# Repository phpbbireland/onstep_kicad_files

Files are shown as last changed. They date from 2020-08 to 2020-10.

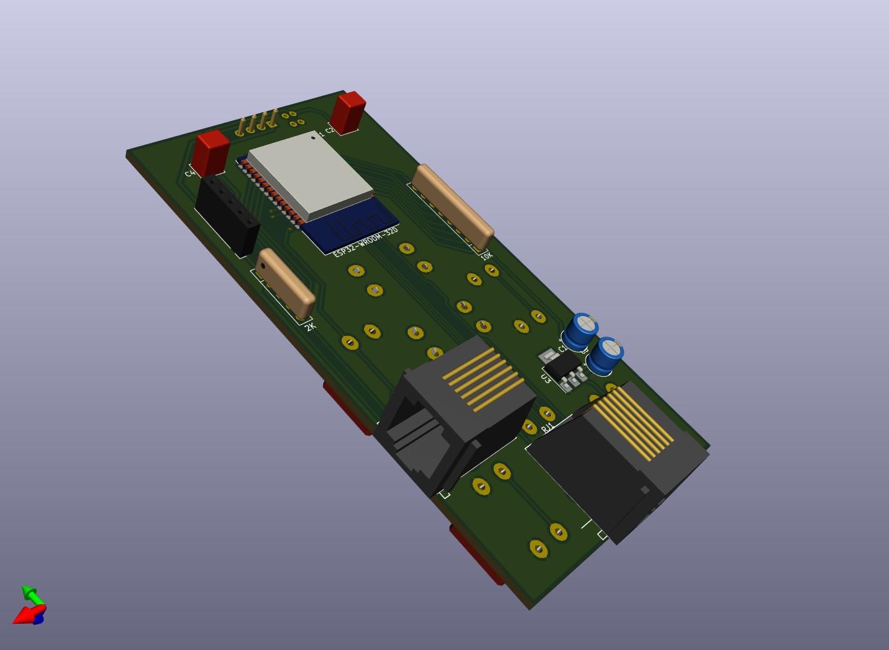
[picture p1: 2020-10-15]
Controller_Version_5.0_SMD_Git/OSHC_ESP32VROOM_Version.jpg

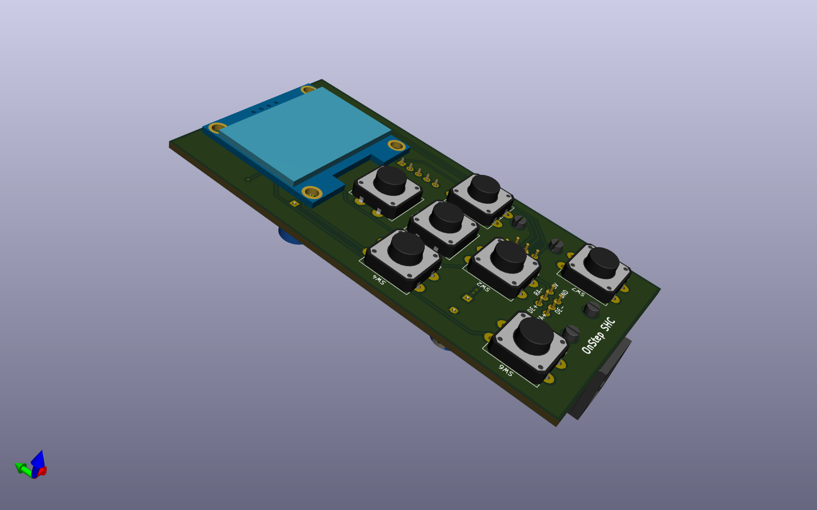
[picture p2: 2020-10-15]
Controller_Version_5.0_SMD_Git/pcb_top.png

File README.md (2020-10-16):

# onstep_kicad_files
Kicad Support Files for OnStep

Here I will Add support files for developing OnStep with Kicad (& FreeCAD where available)...

I have issues access my git repos... appears to be a password/username mismatch... no idea what's up...

The folder: Controller_Version_5.0_SMD_Git contains dev material and is not currently working... possible track errors...

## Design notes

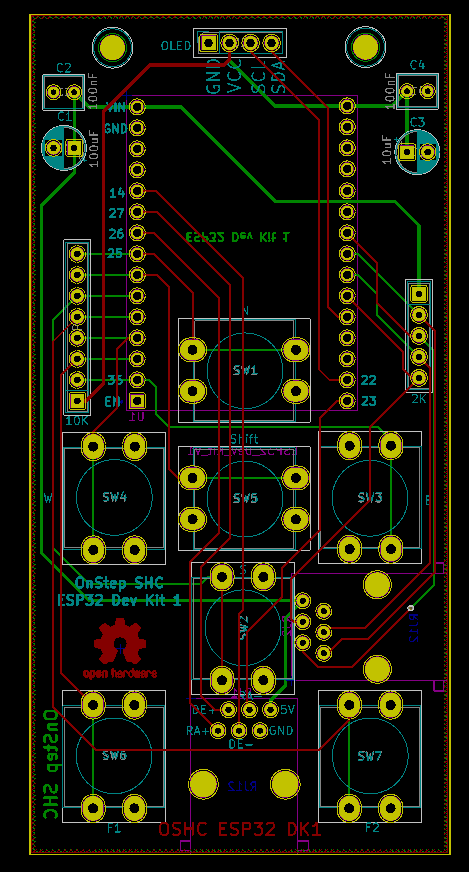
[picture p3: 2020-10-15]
Controller_Version_5.0_SMD_Git/pcb.png

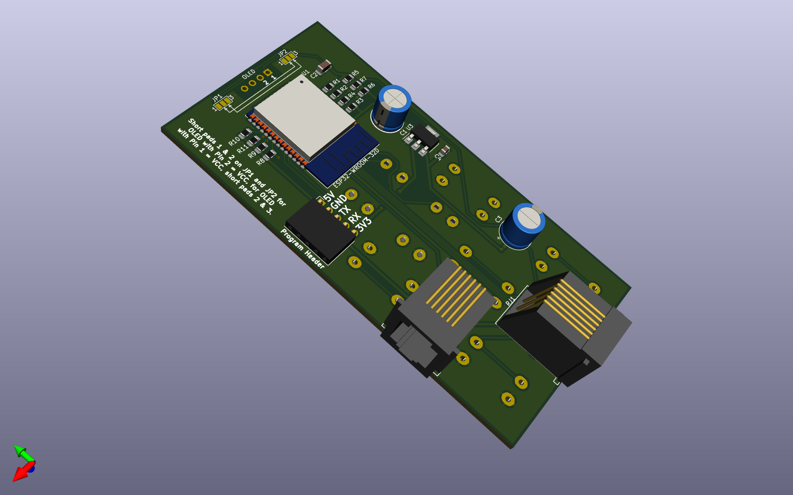
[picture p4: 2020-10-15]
Controller_Version_5.0_SMD_Git/pcb_bottom.png

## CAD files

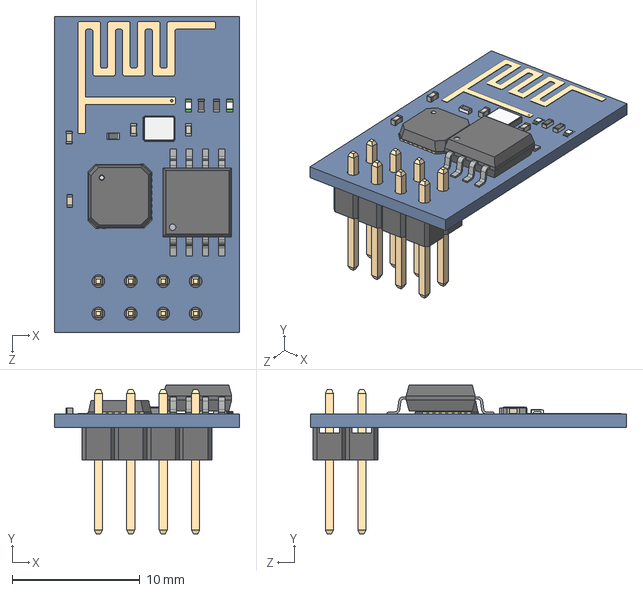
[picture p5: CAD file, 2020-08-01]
ESP8266.step
14.5 x 11.7 x 24.8 mm

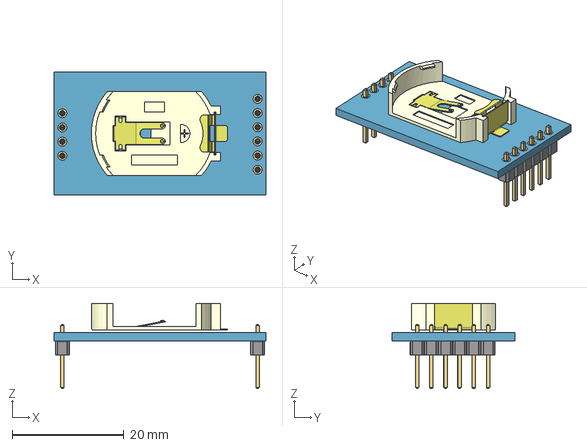
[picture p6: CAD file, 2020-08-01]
DS3231.step
38.0 x 22.0 x 15.3 mm

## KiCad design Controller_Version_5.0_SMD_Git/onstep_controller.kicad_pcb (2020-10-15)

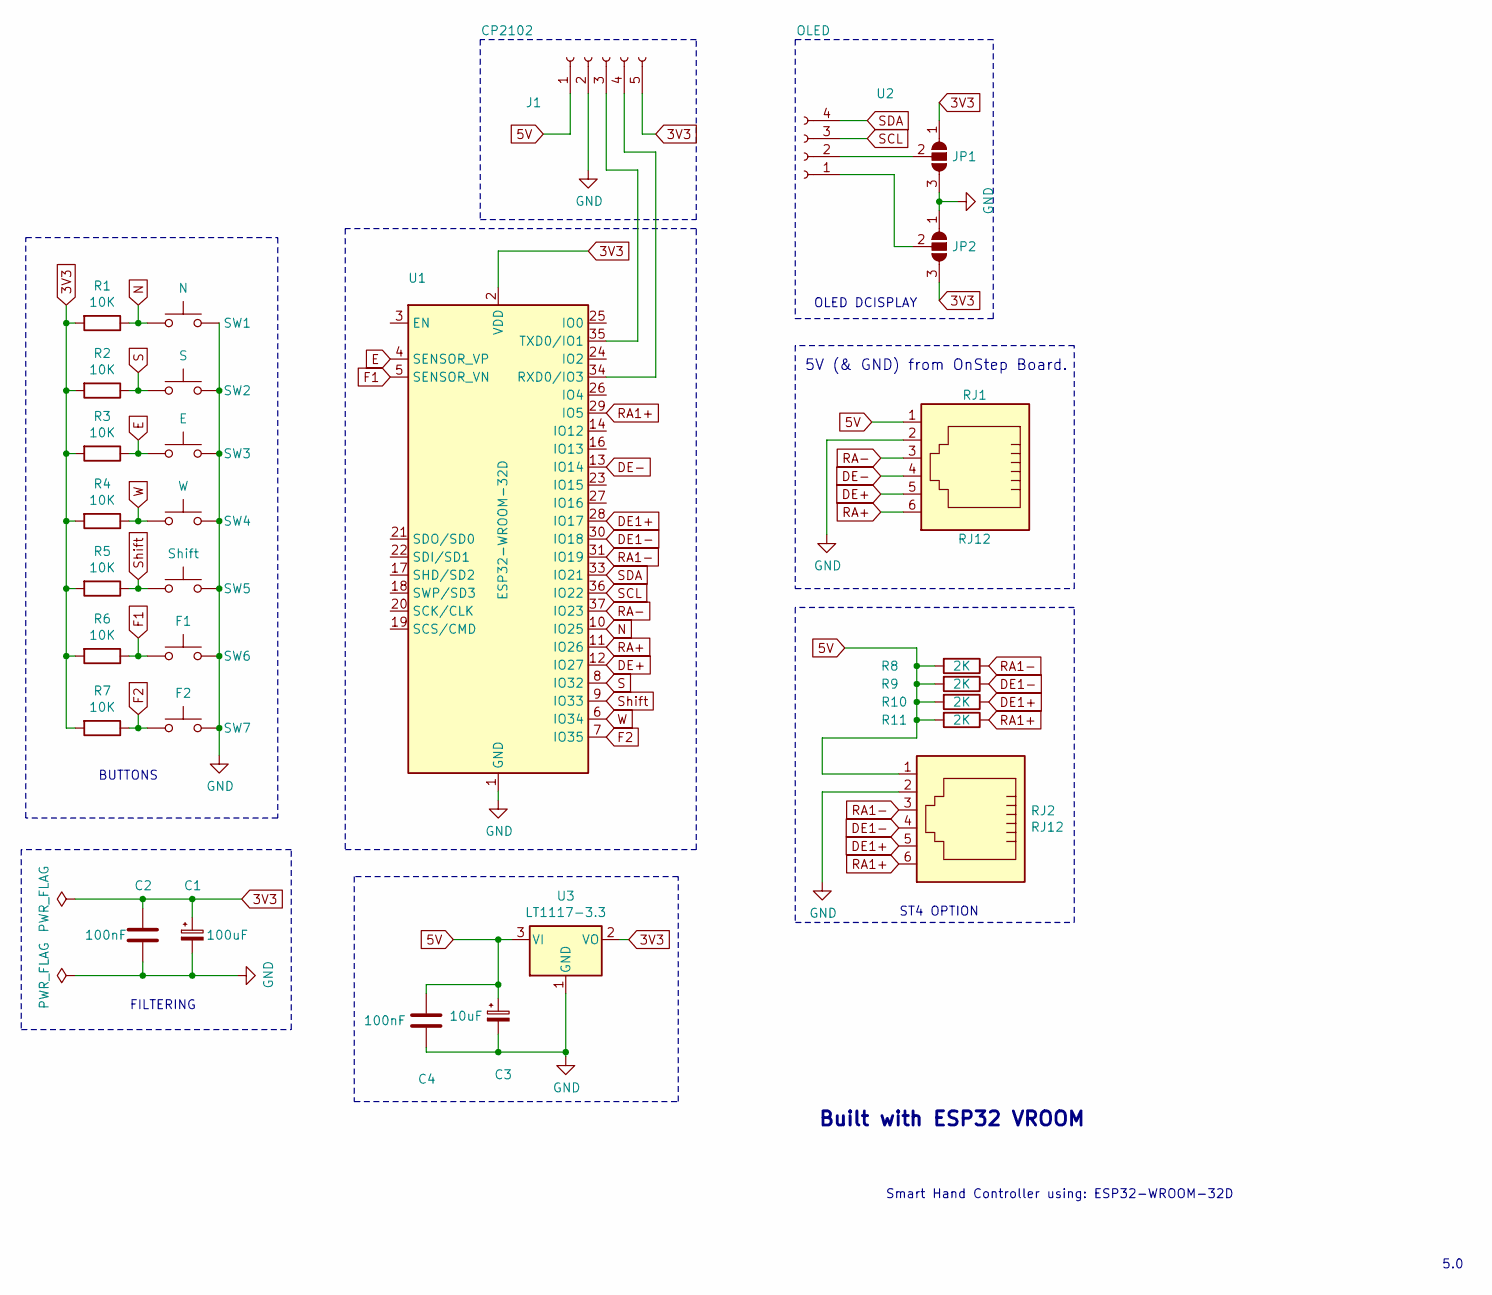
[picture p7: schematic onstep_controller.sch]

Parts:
C1: 100uF; CP_Radial_D8.0mm_P5.00mm
C2: 100nF; C_1206_3216Metric_Pad1.42x1.75mm_HandSolder
C3: 10uF; CP_Radial_D8.0mm_P5.00mm
C4: 100nF; C_0805_2012Metric_Pad1.15x1.40mm_HandSolder
J1: CP2102; PinSocket_1x05_P2.54mm_Horizontal
JP1, JP2: SolderJumper_3_Open; SolderJumper-3_P1.3mm_Open_Pad1.0x1.5mm_NumberLabels
R1, R2, R3, R4, R5, R6, R7: 10K; R_0805_2012Metric_Pad1.15x1.40mm_HandSolder
R8, R9, R10, R11: 2K; R_0805_2012Metric_Pad1.15x1.40mm_HandSolder
RJ1, RJ2: RJ12; RJ12_IreR2
SW1: N; SW_PUSH-12mm_
SW2: S; SW_PUSH-12mm_
SW3: E; SW_PUSH-12mm_
SW4: W; SW_PUSH-12mm_
SW5: Shift; SW_PUSH-12mm_
SW6: F1; SW_PUSH-12mm_
SW7: F2; SW_PUSH-12mm_
U1: ESP32-WROOM-32D; ESP32-WROOM-32x
U2: OLED; PinSocket_1x04_P2.54mm_Vertical
U3: LT1117-3.3; SOT-223-3_TabPin2

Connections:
3V3: C1.1, C2.1, J1.5, JP1.1 (A), JP2.3 (B), R1.2, R2.2, R3.2, R4.2, R5.2, R6.2, R7.2, U1.2 (VDD), U3.2 (VO)
5V: C3.1, C4.1, J1.1, R8.2, R9.2, R10.2, R11.2, RJ1.1, RJ2.1, U3.3 (VI)
DE1+: R10.1, RJ2.5, U1.28 (IO17)
DE1-: R9.1, RJ2.4, U1.30 (IO18)
DE+: RJ1.5, U1.12 (IO27)
DE-: RJ1.4, U1.13 (IO14)
E: R3.1, SW3.1, U1.4 (SENSOR_VP)
F1: R6.1, SW6.1, U1.5 (SENSOR_VN)
F2: R7.1, SW7.1, U1.7 (IO35)
GND: C1.2, C2.2, C3.2, C4.2, J1.2, JP1.3 (B), JP2.1 (A), RJ1.2, RJ2.2, SW1.2, SW2.2, SW3.2, SW4.2, SW5.2, SW6.2, SW7.2, U1.1 (GND), U1.15 (GND), U1.38 (GND), U3.1 (GND)
N: R1.1, SW1.1, U1.10 (IO25)
unnamed: J1.3, U1.35 (TXD0/IO1)
unnamed: J1.4, U1.34 (RXD0/IO3)
unnamed: JP1.2 (C), U2.2
unnamed: JP2.2 (C), U2.1
RA1+: R11.1, RJ2.6, U1.29 (IO5)
RA1-: R8.1, RJ2.3, U1.31 (IO19)
RA+: RJ1.6, U1.11 (IO26)
RA-: RJ1.3, U1.37 (IO23)
S: R2.1, SW2.1, U1.8 (IO32)
SCL: U1.36 (IO22), U2.3
SDA: U1.33 (IO21), U2.4
Shift: R5.1, SW5.1, U1.9 (IO33)
W: R4.1, SW4.1, U1.6 (IO34)

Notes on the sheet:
Smart Hand Controller using: ESP32-WROOM-32D
5.0
Built with ESP32 VROOM
5V (& GND) from OnStep Board.
OLED DCISPLAY
ST4 OPTION
FILTERING
BUTTONS

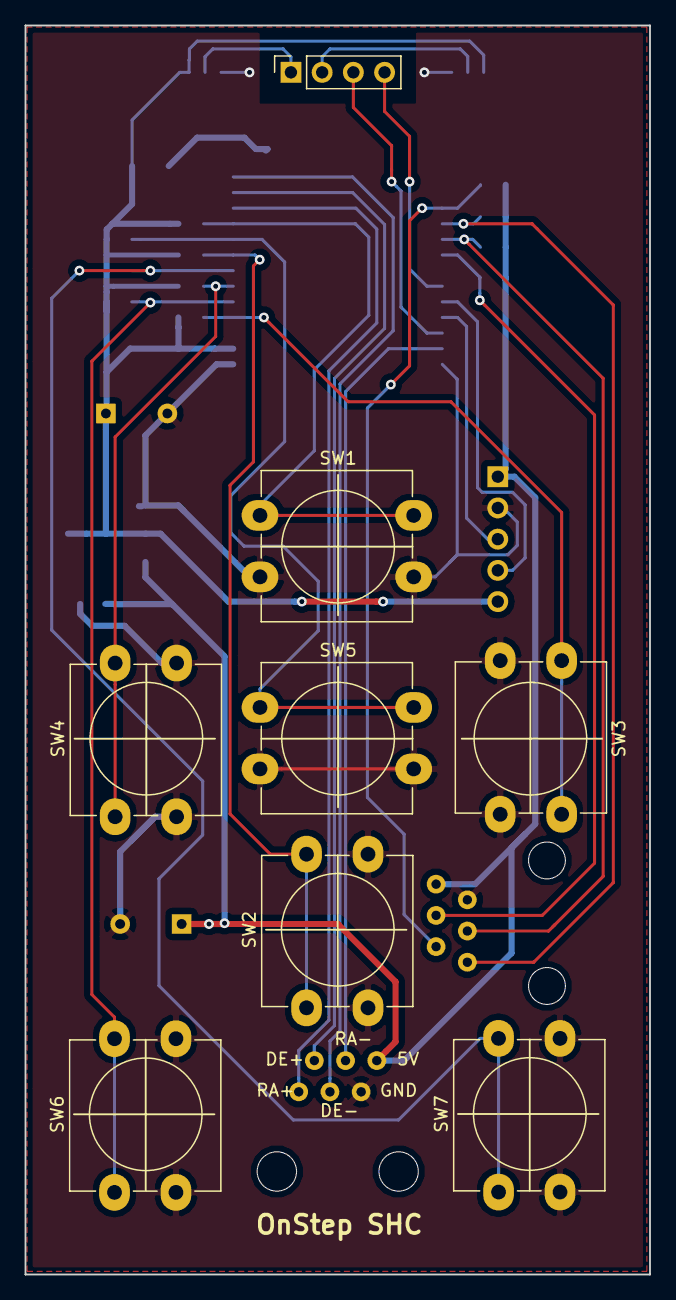
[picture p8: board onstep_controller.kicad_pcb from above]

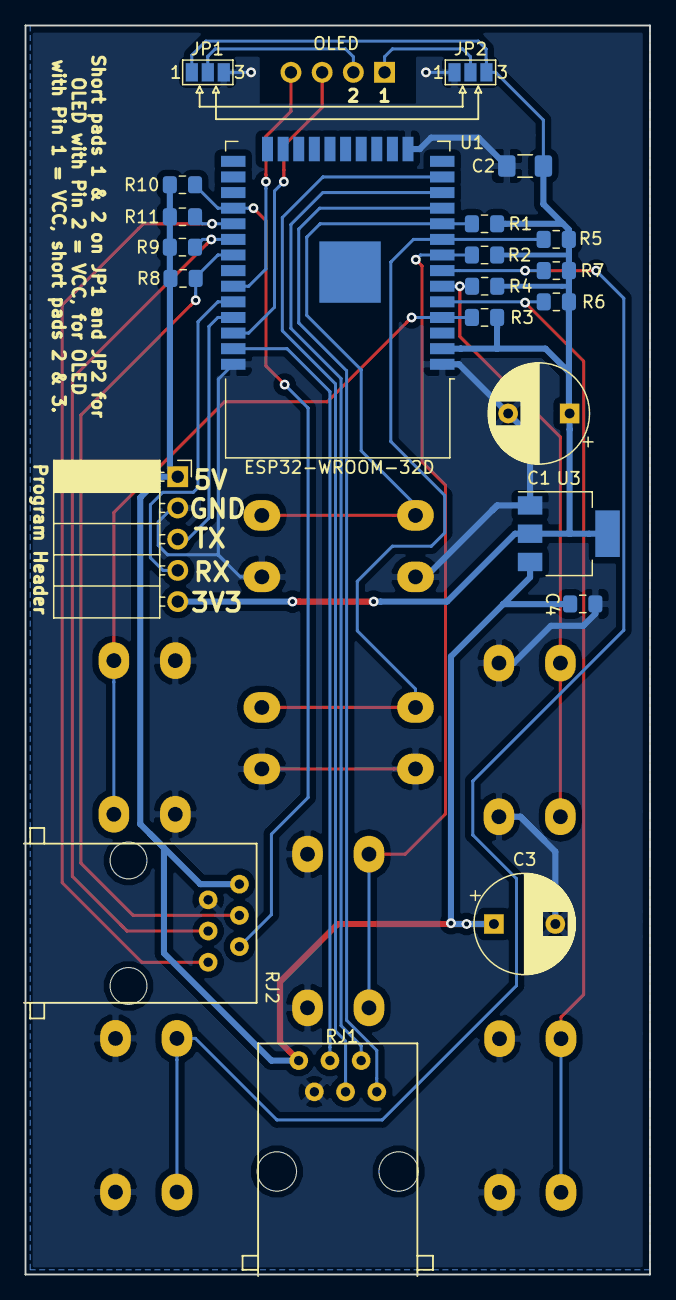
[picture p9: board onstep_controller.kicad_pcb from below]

Board: 2 copper layers, 50.8 x 101.6 mm, 30 parts (22 on the bottom side), 24 nets.

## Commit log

2020-08-01 More test files
    [DS3231.step]
2020-08-01 Two more test files
    I can't access from git directly... no idea why...
    [ESP8266.step]
2020-10-15 Adding OnStep SHC using Wroom Version
    Smart Hand Controller using: ESP32-WROOM-32D
    [onstep_controller.kicad_pcb, onstep_controller.sch]
